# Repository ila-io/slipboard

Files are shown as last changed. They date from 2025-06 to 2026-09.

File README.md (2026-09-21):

# slipboard
I designed this macropad to slip onto the top of my Surface Pro, since I like to take the keyboard off to draw and watch media in tablet mode, but I also like to be able to copy and paste, undo, and the like. The pen buttons are extremely unhelpful in their utility to say the least, so I created a macropad! As of now, the button layout is as such: 

| undo | copy | paste | delete |
| ---- | ---- | ----- | --- |

The encoder press is used to pause/play music, and as of now it's rotation just bound to f13/f14, which I'm hoping to make change my pen size in Krita! 

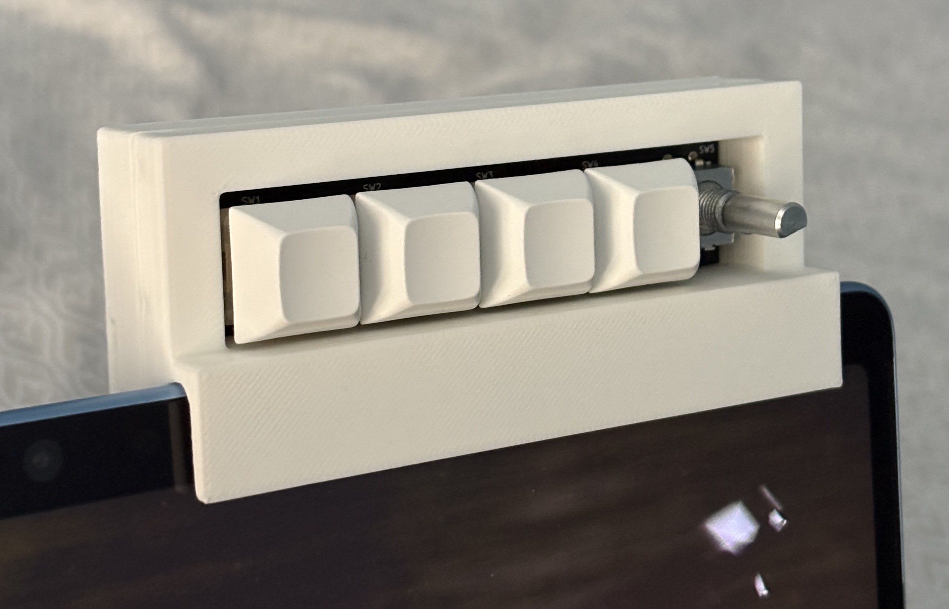
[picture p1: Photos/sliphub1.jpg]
picture of the finished sliphub


## CAD
Here's the slipboard slipped onto a mockup section of the Surface Pro! 
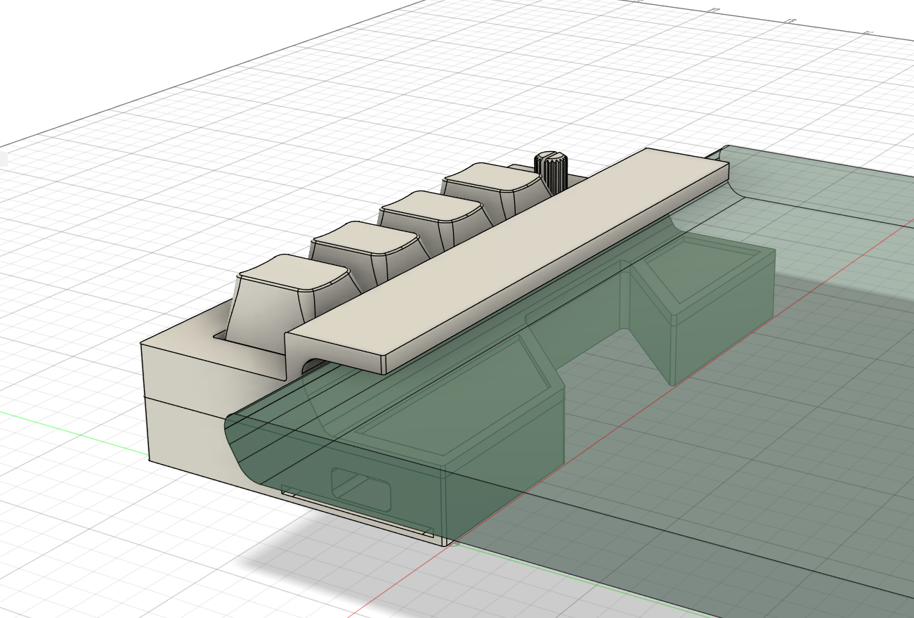
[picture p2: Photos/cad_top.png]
a screenshot from Fusion360 containing my hackpad

There are soft sliders in the insets to allow the device to slide on and off safely, and stay secured while in use!

### back/bottom
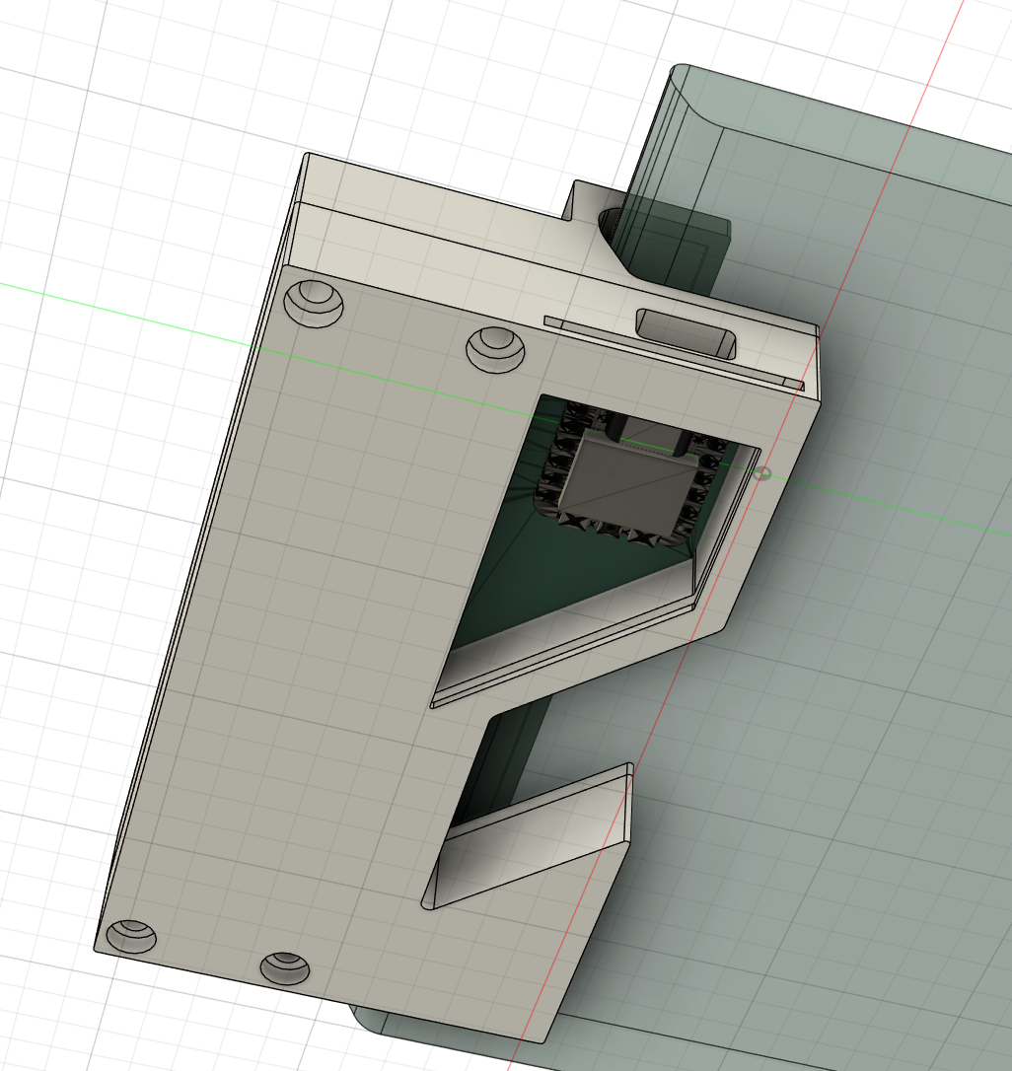
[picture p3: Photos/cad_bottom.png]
a screenshot of the bottom of my hackpad

I left a slot here for an acrylic sheet to slide in, since I like the look of the PCB and I put a design on the silkscreen that I don't want covered up :3

### disassembled
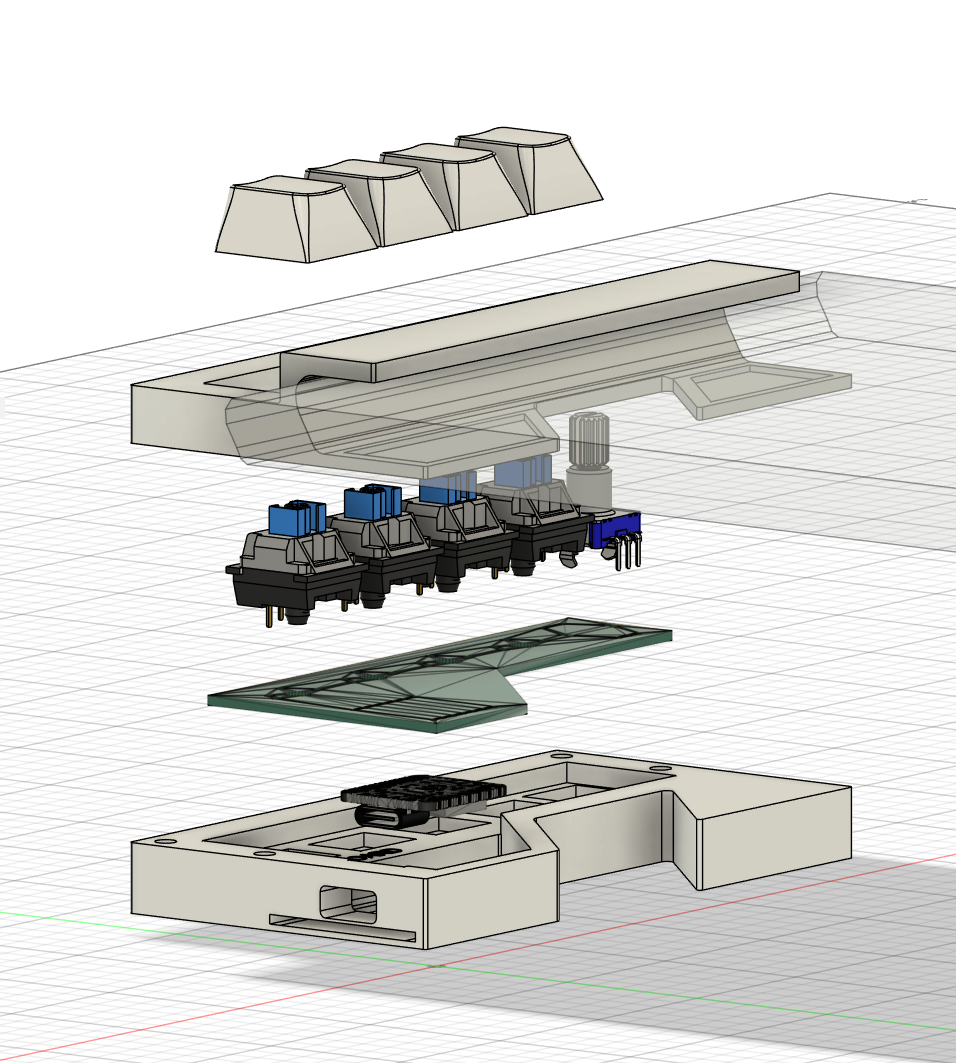
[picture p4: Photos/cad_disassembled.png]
a screenshot of the disassembled hackpad in Fusion360

## PCB/Schematic
I'm a big fan of the look of the raw traces on the PCB, so I utilized that and the silkscreen to make a design that will show through on the backside of the slipboard when its on my tablet! 
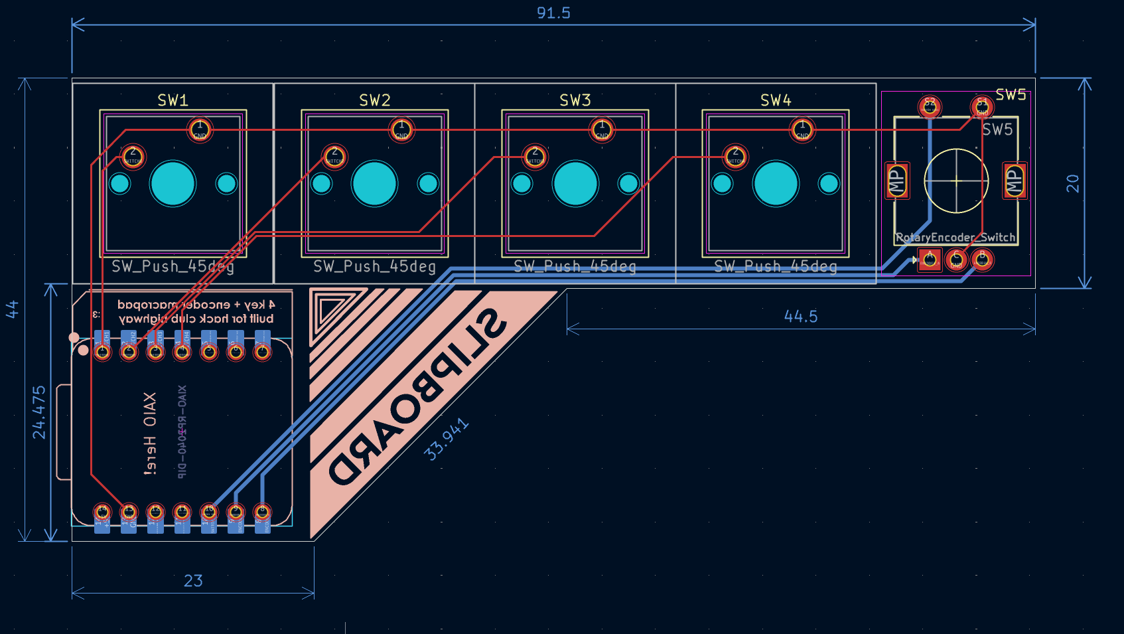
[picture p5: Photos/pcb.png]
a screenshot of the hackpad's pcb in kicad

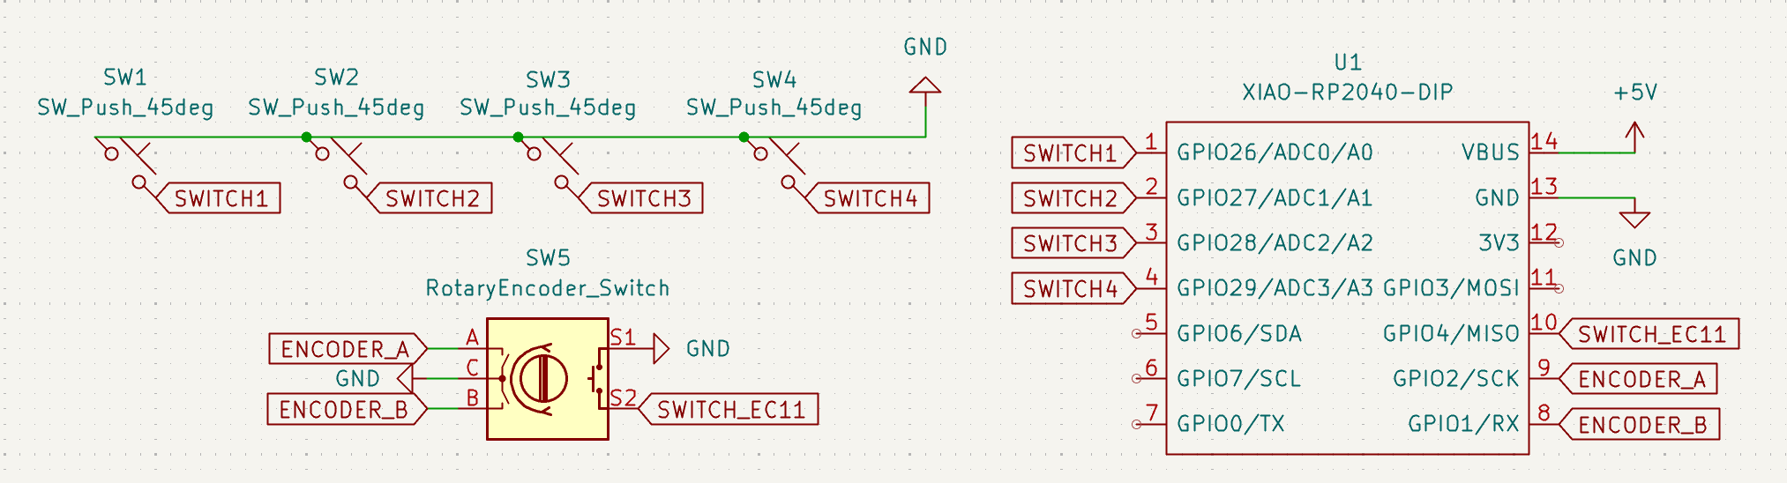
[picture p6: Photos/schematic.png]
a screenshot of the hackpad's schematic in kicad


### [demo video!](https://youtu.be/LWUtzJrfr4w)

## BOM
| Quantity | Material |
|---|---|
| 1 | Seeed XIAO RP2040 | 
| 1 | PCB |
| 1 | EC11 Rotary encoder |
| 4 | MX-Style switches |
| 4 | MX Keycaps | 
| 1 | 3D printed Case (2pts) |
| 4 | M3x16mm screws |
| 4 | M3X5X4 Heatset Inserts |

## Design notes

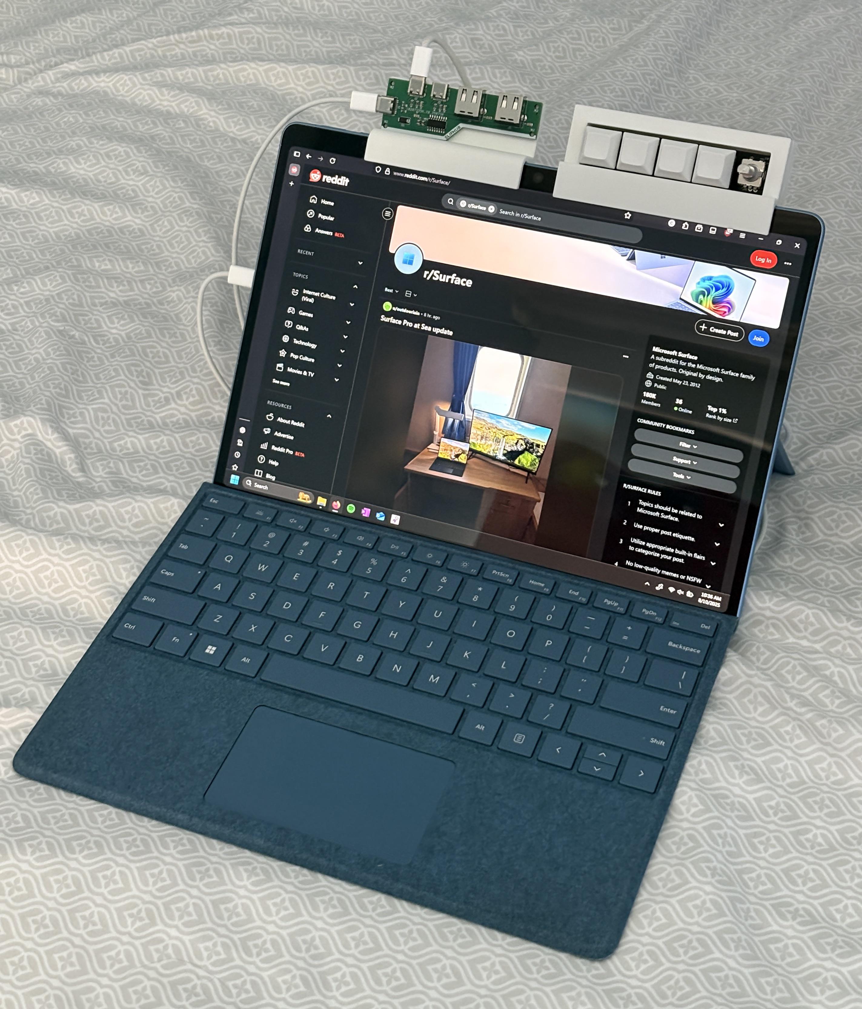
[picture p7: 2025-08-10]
Photos/sliphub.jpeg

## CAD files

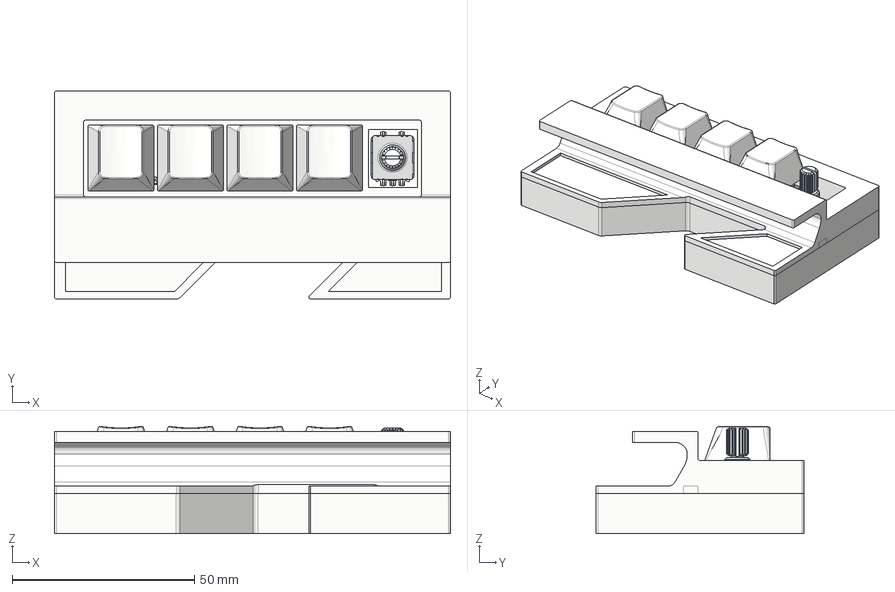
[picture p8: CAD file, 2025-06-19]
CAD/slipboard_assembled.step
108.5 x 57.0 x 29.4 mm

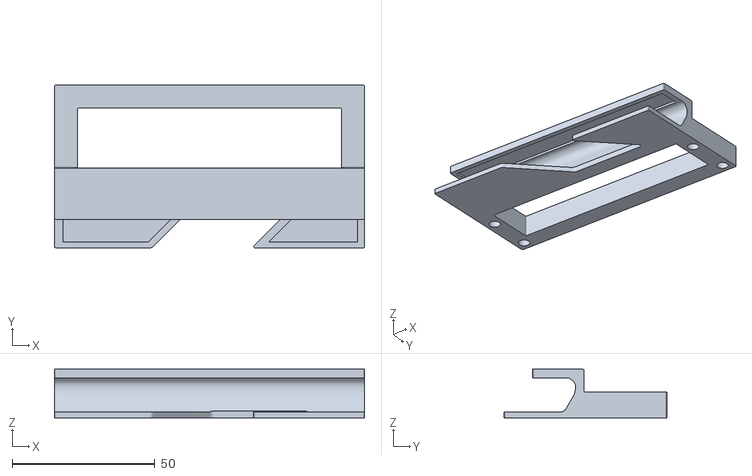
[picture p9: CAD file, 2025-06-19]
production/Top.stl
108.5 x 57.0 x 17.0

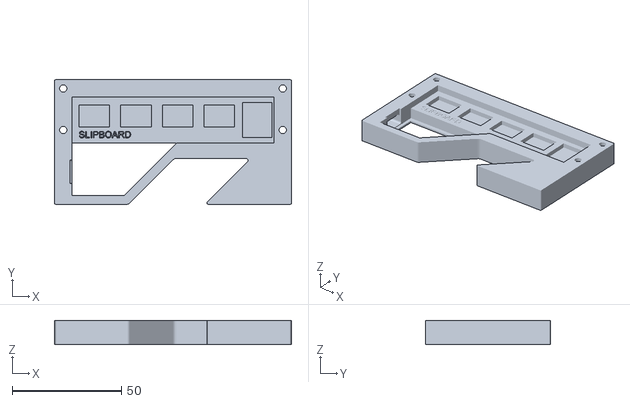
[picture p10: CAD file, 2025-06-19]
production/Bottom.stl
108.5 x 57.0 x 11.0

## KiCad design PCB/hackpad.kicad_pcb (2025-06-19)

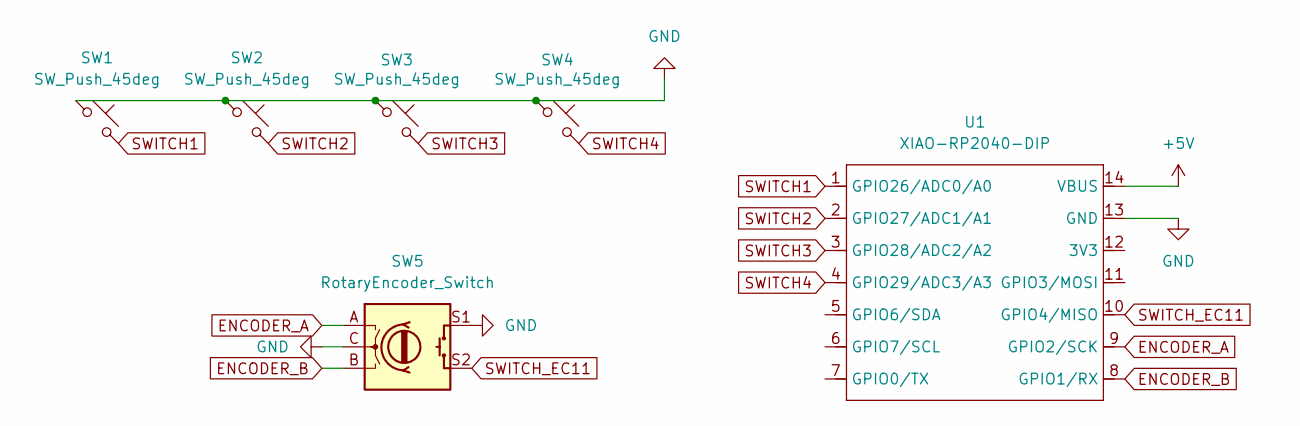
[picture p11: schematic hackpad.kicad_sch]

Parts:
SW1, SW2, SW3, SW4: SW_Push_45deg; SW_Cherry_MX_1.00u_PCB
SW5: RotaryEncoder_Switch; RotaryEncoder_Alps_EC11E-Switch_Vertical_H20mm
U1: XIAO-RP2040-DIP

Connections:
+5V: U1.14 (VBUS)
ENCODER_A: SW5.A, U1.9 (GPIO2/SCK)
ENCODER_B: SW5.B, U1.8 (GPIO1/RX)
GND: SW1.1, SW2.1, SW3.1, SW4.1, SW5.C, SW5.S1, U1.13 (GND)
SWITCH1: SW1.2, U1.1 (GPIO26/ADC0/A0)
SWITCH2: SW2.2, U1.2 (GPIO27/ADC1/A1)
SWITCH3: SW3.2, U1.3 (GPIO28/ADC2/A2)
SWITCH4: SW4.2, U1.4 (GPIO29/ADC3/A3)
SWITCH_EC11: SW5.S2, U1.10 (GPIO4/MISO)

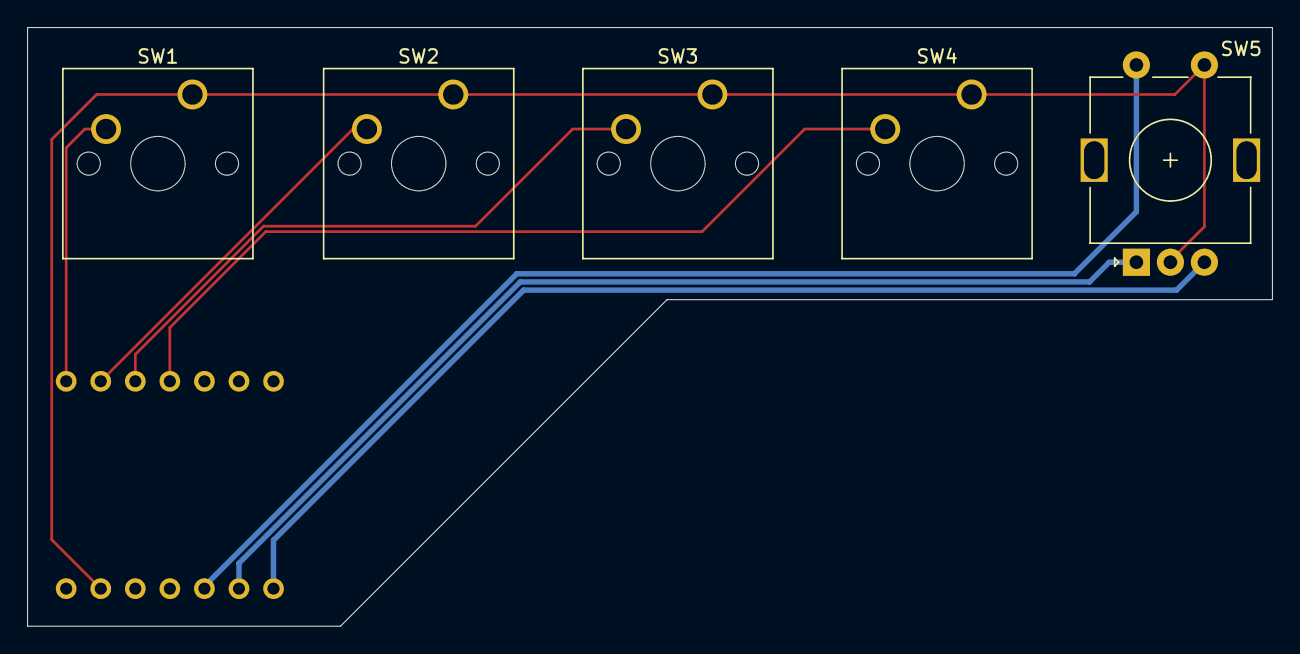
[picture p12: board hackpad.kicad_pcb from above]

Board: 2 copper layers, 91.5 x 44.0 mm, 6 parts (1 on the bottom side), 8 nets.

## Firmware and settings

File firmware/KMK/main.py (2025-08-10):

import board

from kmk.kmk_keyboard import KMKKeyboard
from kmk.scanners.keypad import KeysScanner
from kmk.keys import KC
from kmk.modules.macros import Press, Release, Tap, Macros
from kmk.modules.encoder import EncoderHandler

# === Setup ===
keyboard = KMKKeyboard()

# Define button pins
PINS = [board.D0, board.D1, board.D2, board.D3]
keyboard.matrix = KeysScanner(
    pins=PINS,
    value_when_pressed=False,
)

# === Macros ===
macros = Macros()
keyboard.modules.append(macros)

# === Encoder Setup ===
encoder = EncoderHandler()

# Use (A, B, Button, reverse)
encoder.pins = (
    (board.D7, board.D8, board.D9, False),
)

# Encoder actions: (CCW, CW, PRESS)
encoder.map = (
    (KC.F13, KC.PAUSE, KC.F14),
)

keyboard.modules.append(encoder)

# === Macros ===
UNDO = KC.MACRO(
    Press(KC.LCTL),
    Tap(KC.Z),
    Release(KC.LCTL)
)
COPY = KC.MACRO(
    Press(KC.LCTL),
    Tap(KC.C),
    Release(KC.LCTL)
)
PASTE = KC.MACRO(
    Press(KC.LCTL),
    Tap(KC.V),
    Release(KC.LCTL)
)

# === Keymap ===
keyboard.keymap = [
    [UNDO, KC.DELETE, COPY, PASTE]
]


if __name__ == '__main__':
    keyboard.go()

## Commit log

2025-06-19 Add all files
    [Bottom.stl, Top.stl, hackpad.kicad_pcb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]
2025-06-29 add cad photos to repo
